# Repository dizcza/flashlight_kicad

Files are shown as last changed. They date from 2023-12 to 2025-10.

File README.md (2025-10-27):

# Flashlight PCB design with wooden casing

Kicad PCB design for my wooden flashlight V1 (see https://github.com/dizcza/lasercut_collection). Originally designed by HackLabKyiv residents.

An ordinary 12V LED strip is soldered to the front side of the PCB.

<table>
  <tr>
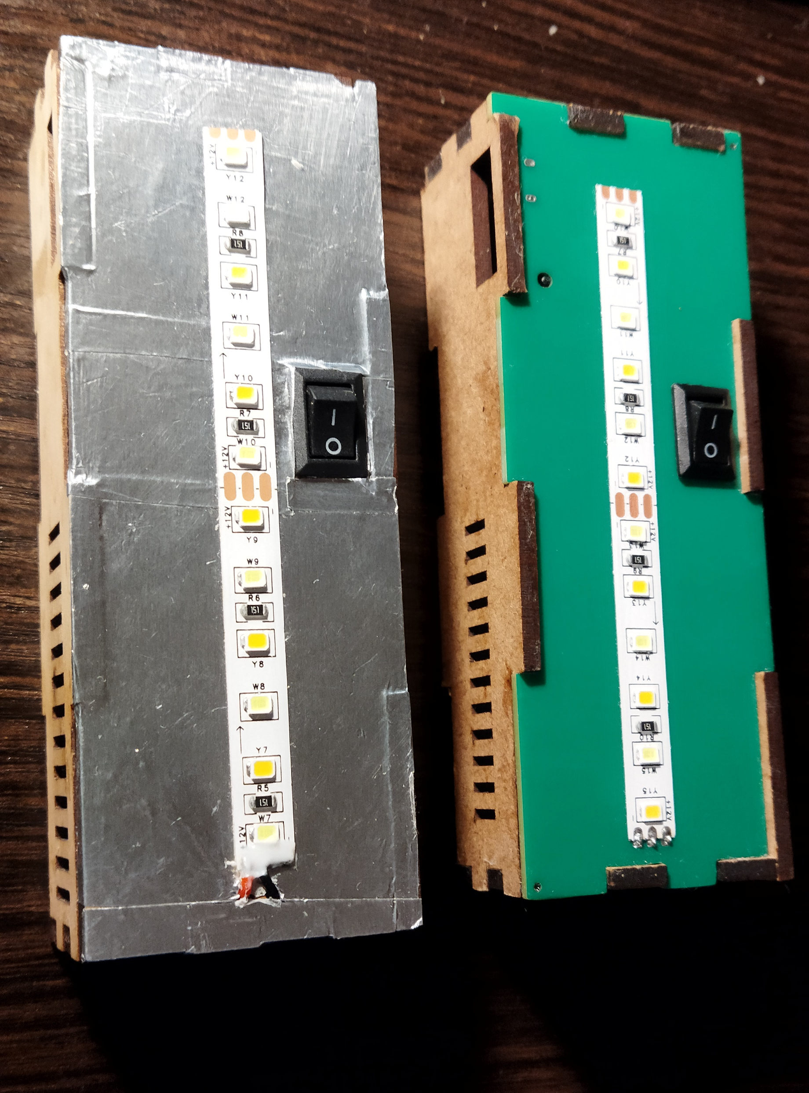
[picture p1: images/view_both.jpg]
   <td></td>
   <td></td>
  </tr>
</table>

## Schematics

[schematics.pdf](schematics.pdf)

## Revisions

<table>
  <tr>
   <th>V1</th>
   <th>V2.1</th>
   <th>V2.2</th>
   <th>V3.0</th>
  </tr>
  <tr>
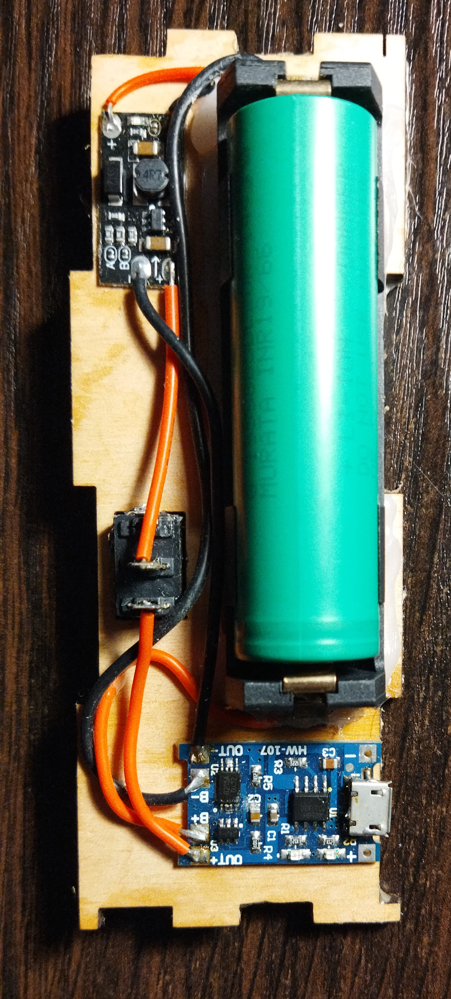
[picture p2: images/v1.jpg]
   <td></td>
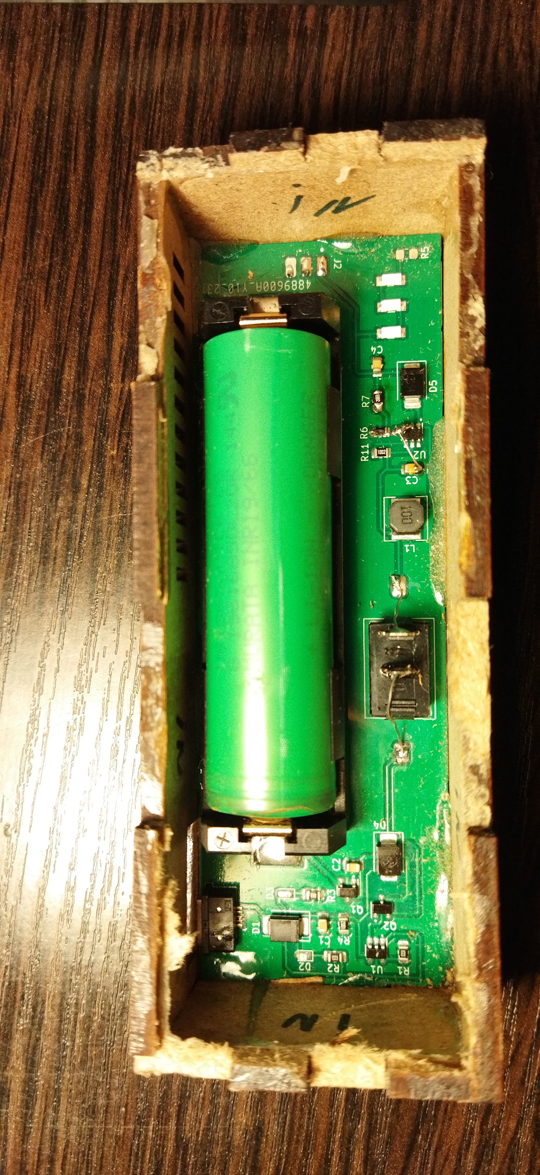
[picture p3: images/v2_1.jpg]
   <td></td>
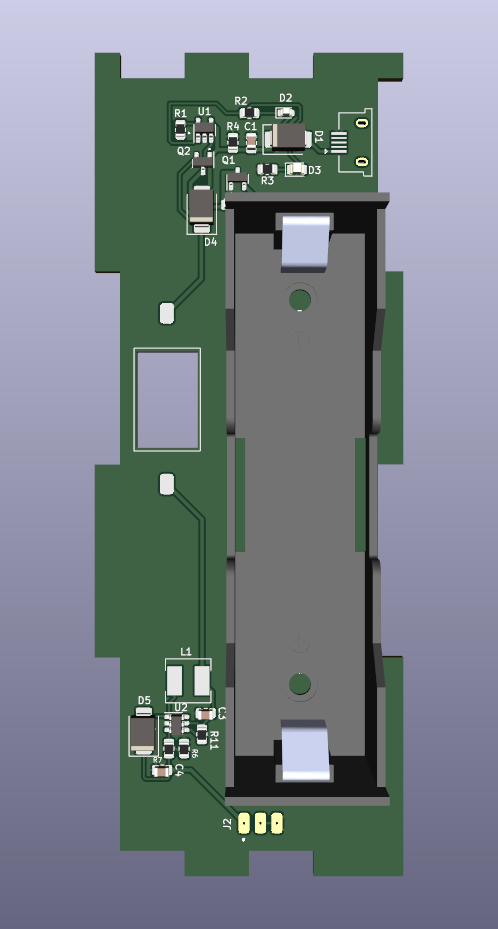
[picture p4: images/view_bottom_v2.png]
   <td></td>
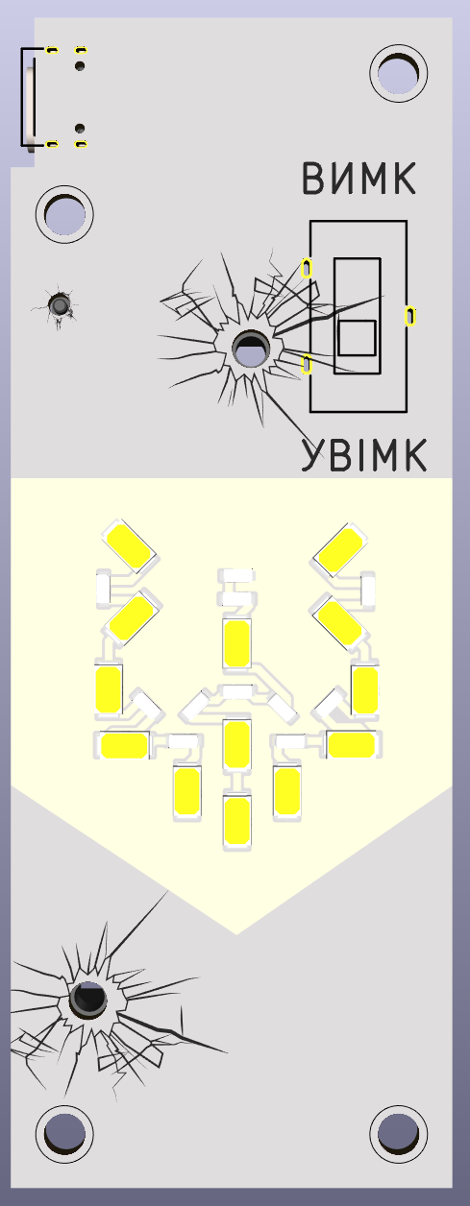
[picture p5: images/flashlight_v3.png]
   <td></td>
  </tr>
</table>

## BOM

|Comment |Designator|Footprint |LCSC |
|---|---|---|---|
|22uF/25V |C1,C3,C4  |Capacitor_SMD:C_0805_2012Metric|C45783  |
|1uF |C2 |Capacitor_SMD:C_0603_1608Metric|C15849  |
|D_Schottky |D1,D4,D5  |Diode_SMD:D_SMB |C22452  |
|USB_B_Micro |J1 |FlashlightLib:USB-1101IPX6-02  |C2858269|
|10uH |L1 |FlashlightLib:L_5.0x5.0 |C2849501|
|HSS2333 |Q2 |Package_TO_SOT_SMD:SOT-23 |C15127  |
|1k |R1,R2,R3  |Resistor_SMD:R_0603_1608Metric |C21190  |
|10k |R4,R6 |Resistor_SMD:R_0603_1608Metric |C25804  |
|200k |R7 |Resistor_SMD:R_0603_1608Metric |C25811  |
|XB4908A |U1 |FlashlightLib:XB4908A |C2998740|
|MT3608 |U2 |Package_TO_SOT_SMD:SOT-23-6 |C84817  |
|TP4057 |U3 |Package_TO_SOT_SMD:TSOT-23-6 |C12044  |
|R6BHC-A05_LED-19-223|U4 |MyFootprints:R6BHC-A05_LED |C131286 |

## Casing

Can be lasercut or 3d-printed.



DXF file: [casing.dxf](./casing/casing.dxf)

OpenSCAD design file: https://github.com/dizcza/lasercut_collection/blob/master/Lampa.scad

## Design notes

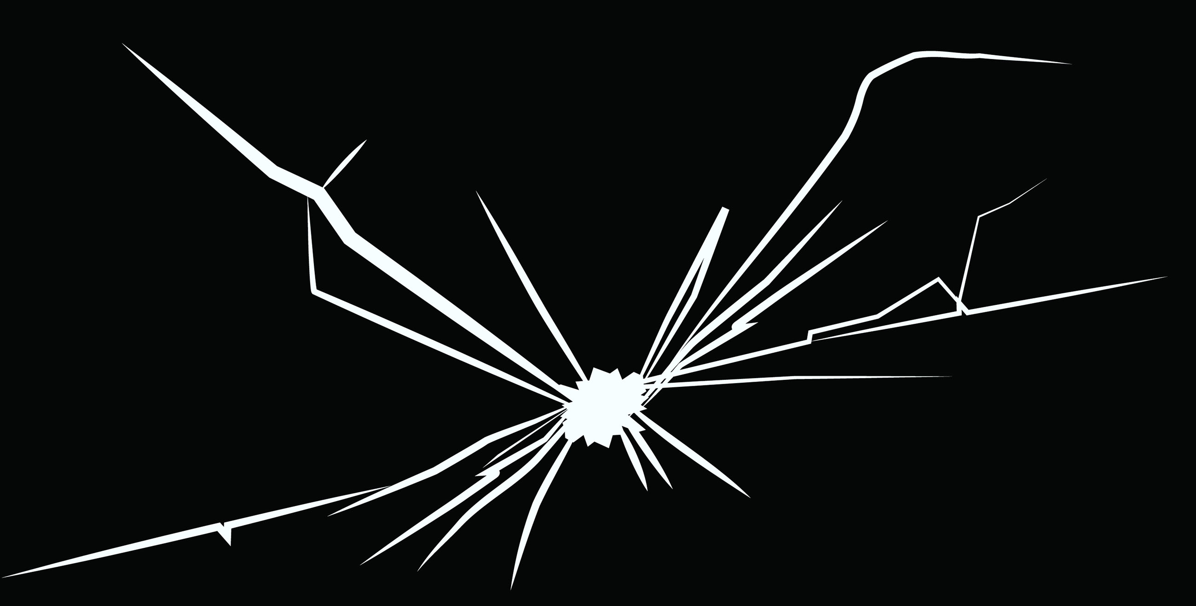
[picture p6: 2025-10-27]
images/bullet-hole/patch1.png

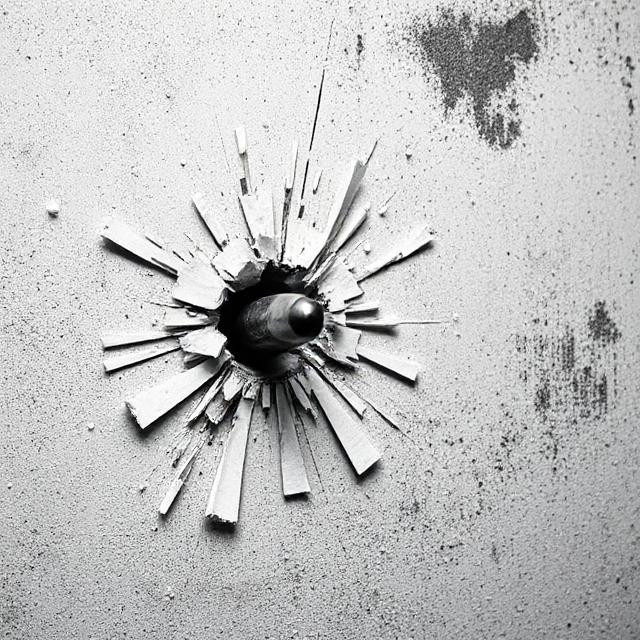
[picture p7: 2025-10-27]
images/bullet-hole/ai3.jpeg

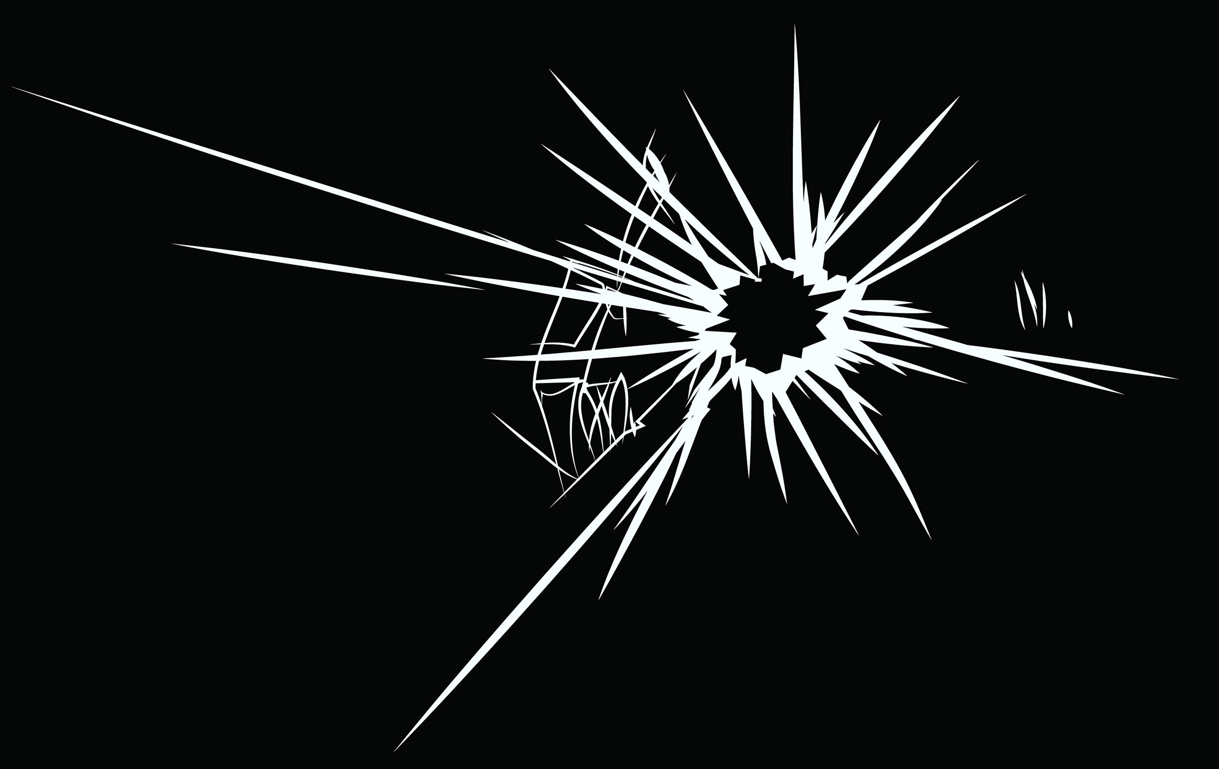
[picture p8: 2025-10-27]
images/bullet-hole/patch3.png

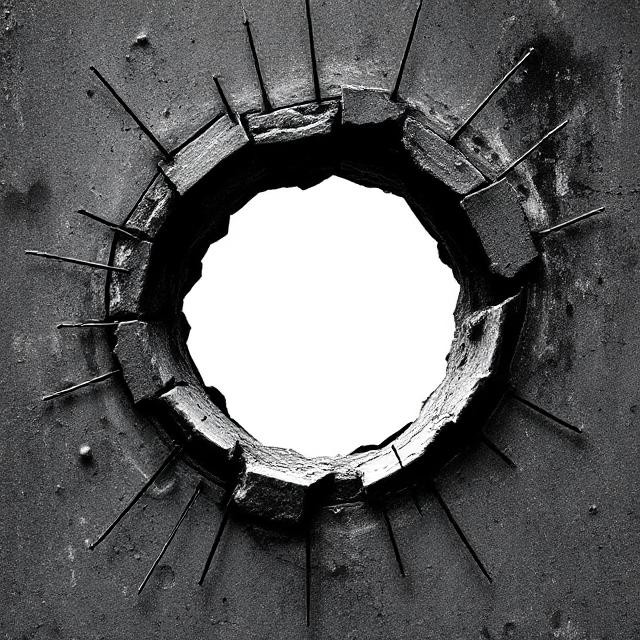
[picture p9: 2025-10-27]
images/bullet-hole/ai4.jpg

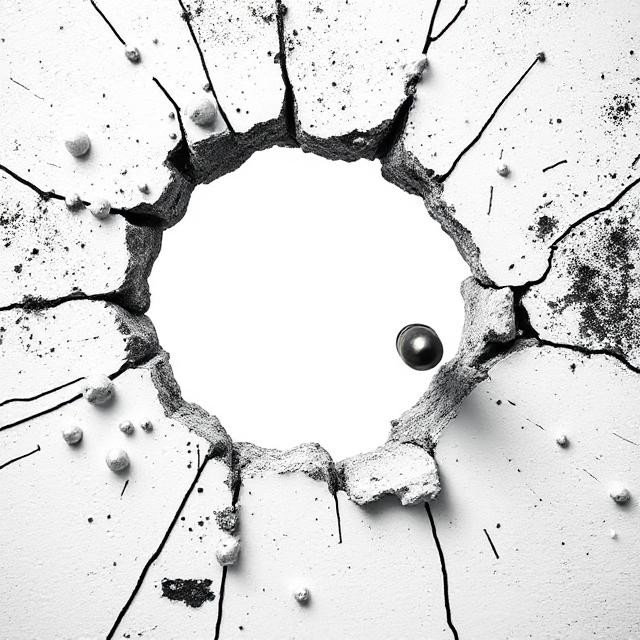
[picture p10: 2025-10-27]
images/bullet-hole/ai2.jpeg

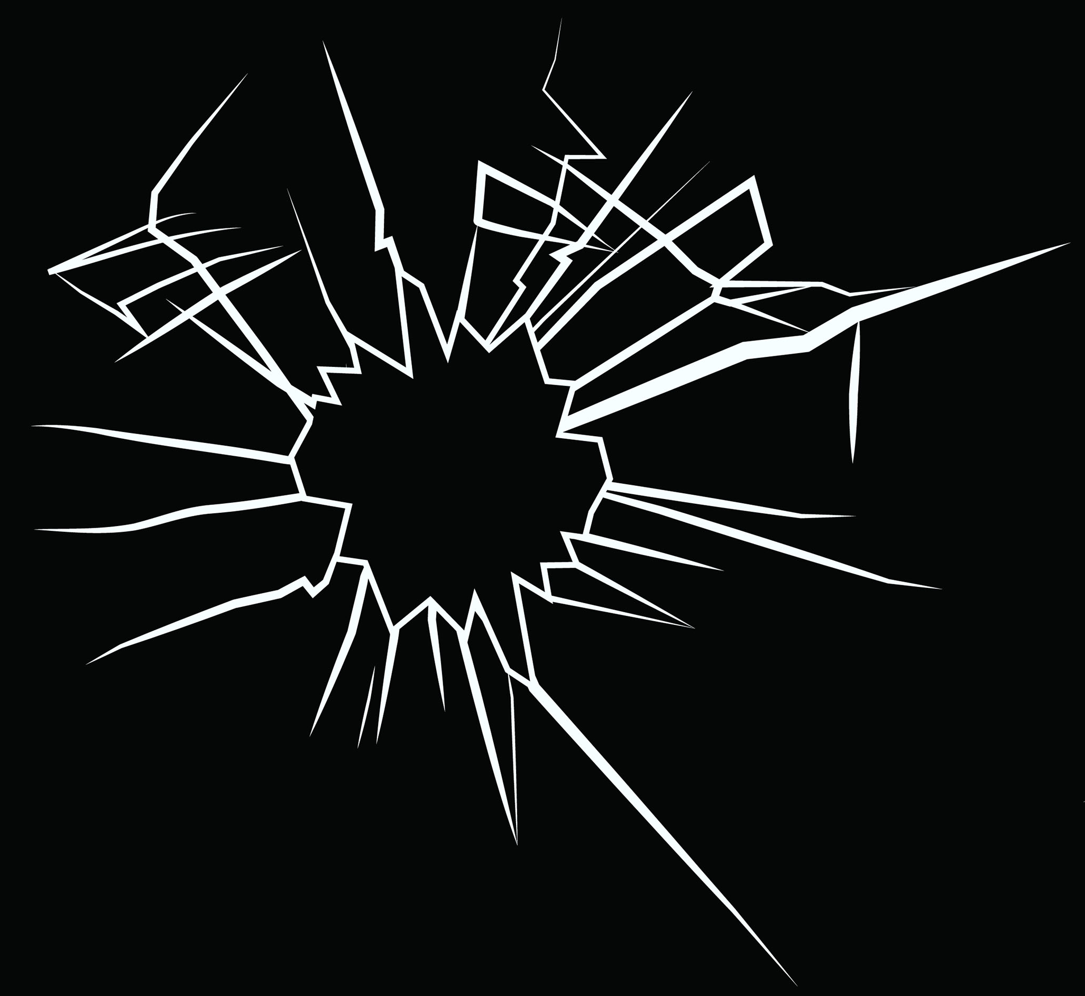
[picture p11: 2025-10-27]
images/bullet-hole/patch2.png

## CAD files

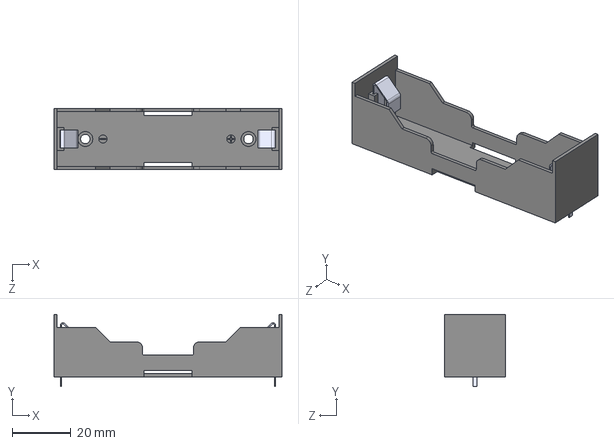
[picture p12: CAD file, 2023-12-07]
3dmodels/BH-18650-PC--3DModel-STEP-56544.STEP
77.7 x 24.6 x 20.9 mm

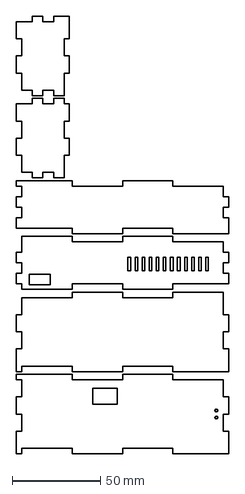
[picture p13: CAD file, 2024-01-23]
casing/casing.dxf
120.0 x 247.8 mm

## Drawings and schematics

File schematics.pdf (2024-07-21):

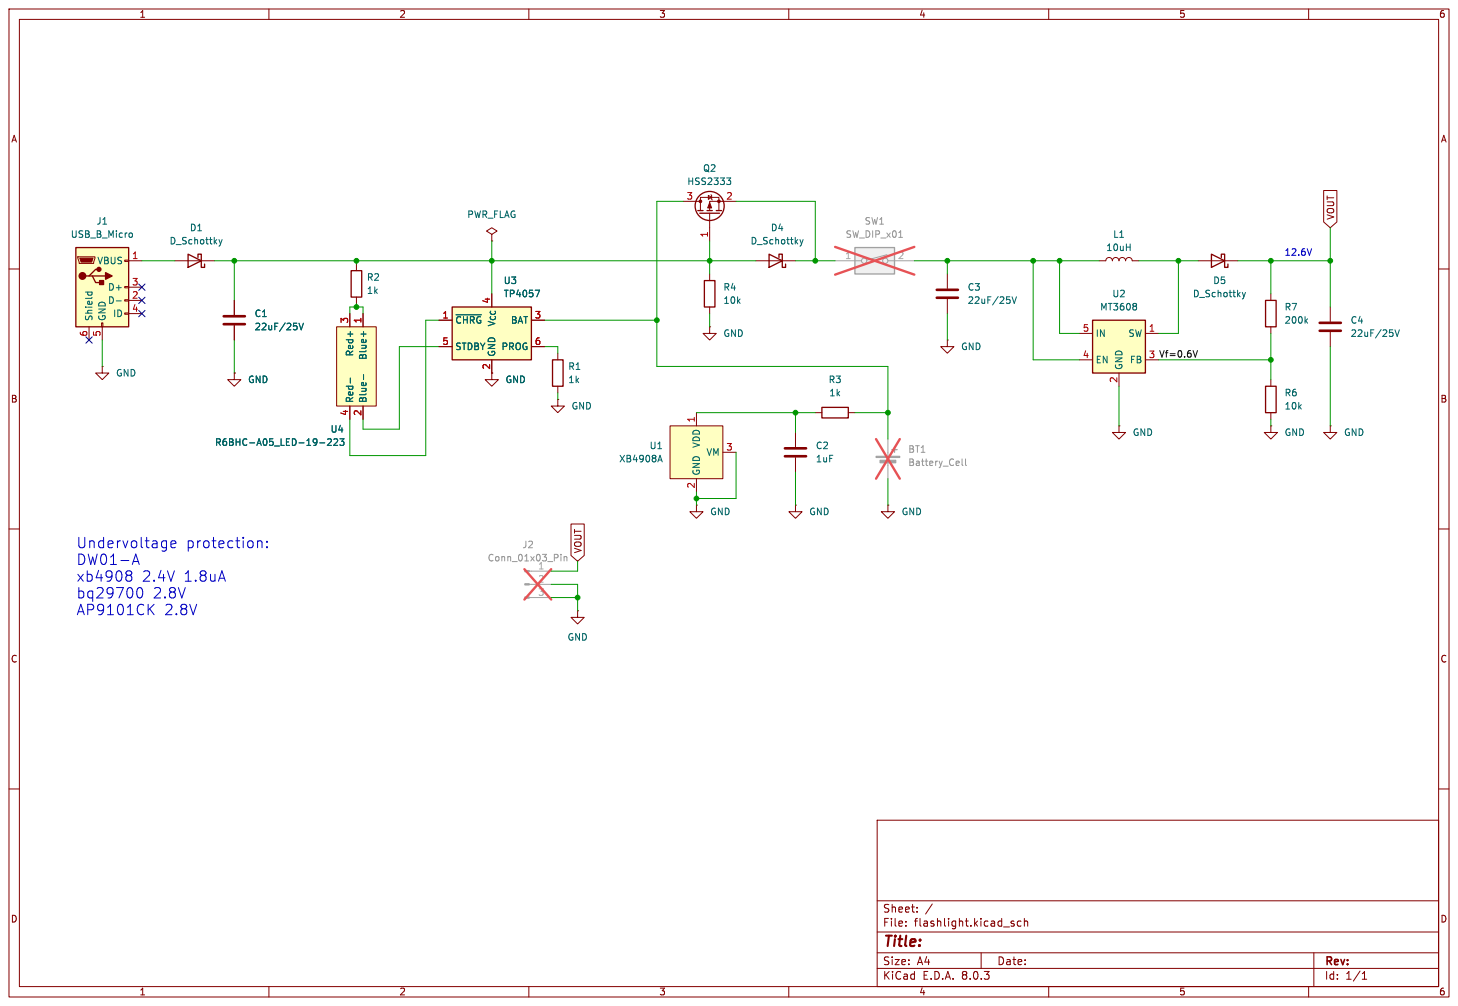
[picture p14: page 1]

2 BAT 3 V_{CC} 4 STDBY 5 PROG 6 U3 TP4057 GND VDD

2 BAT 3 V_{CC} 4 STDBY 5 PROG 6 C1

Id: 1/1 Title: File: flashlight.kicad_sch Sheet: /

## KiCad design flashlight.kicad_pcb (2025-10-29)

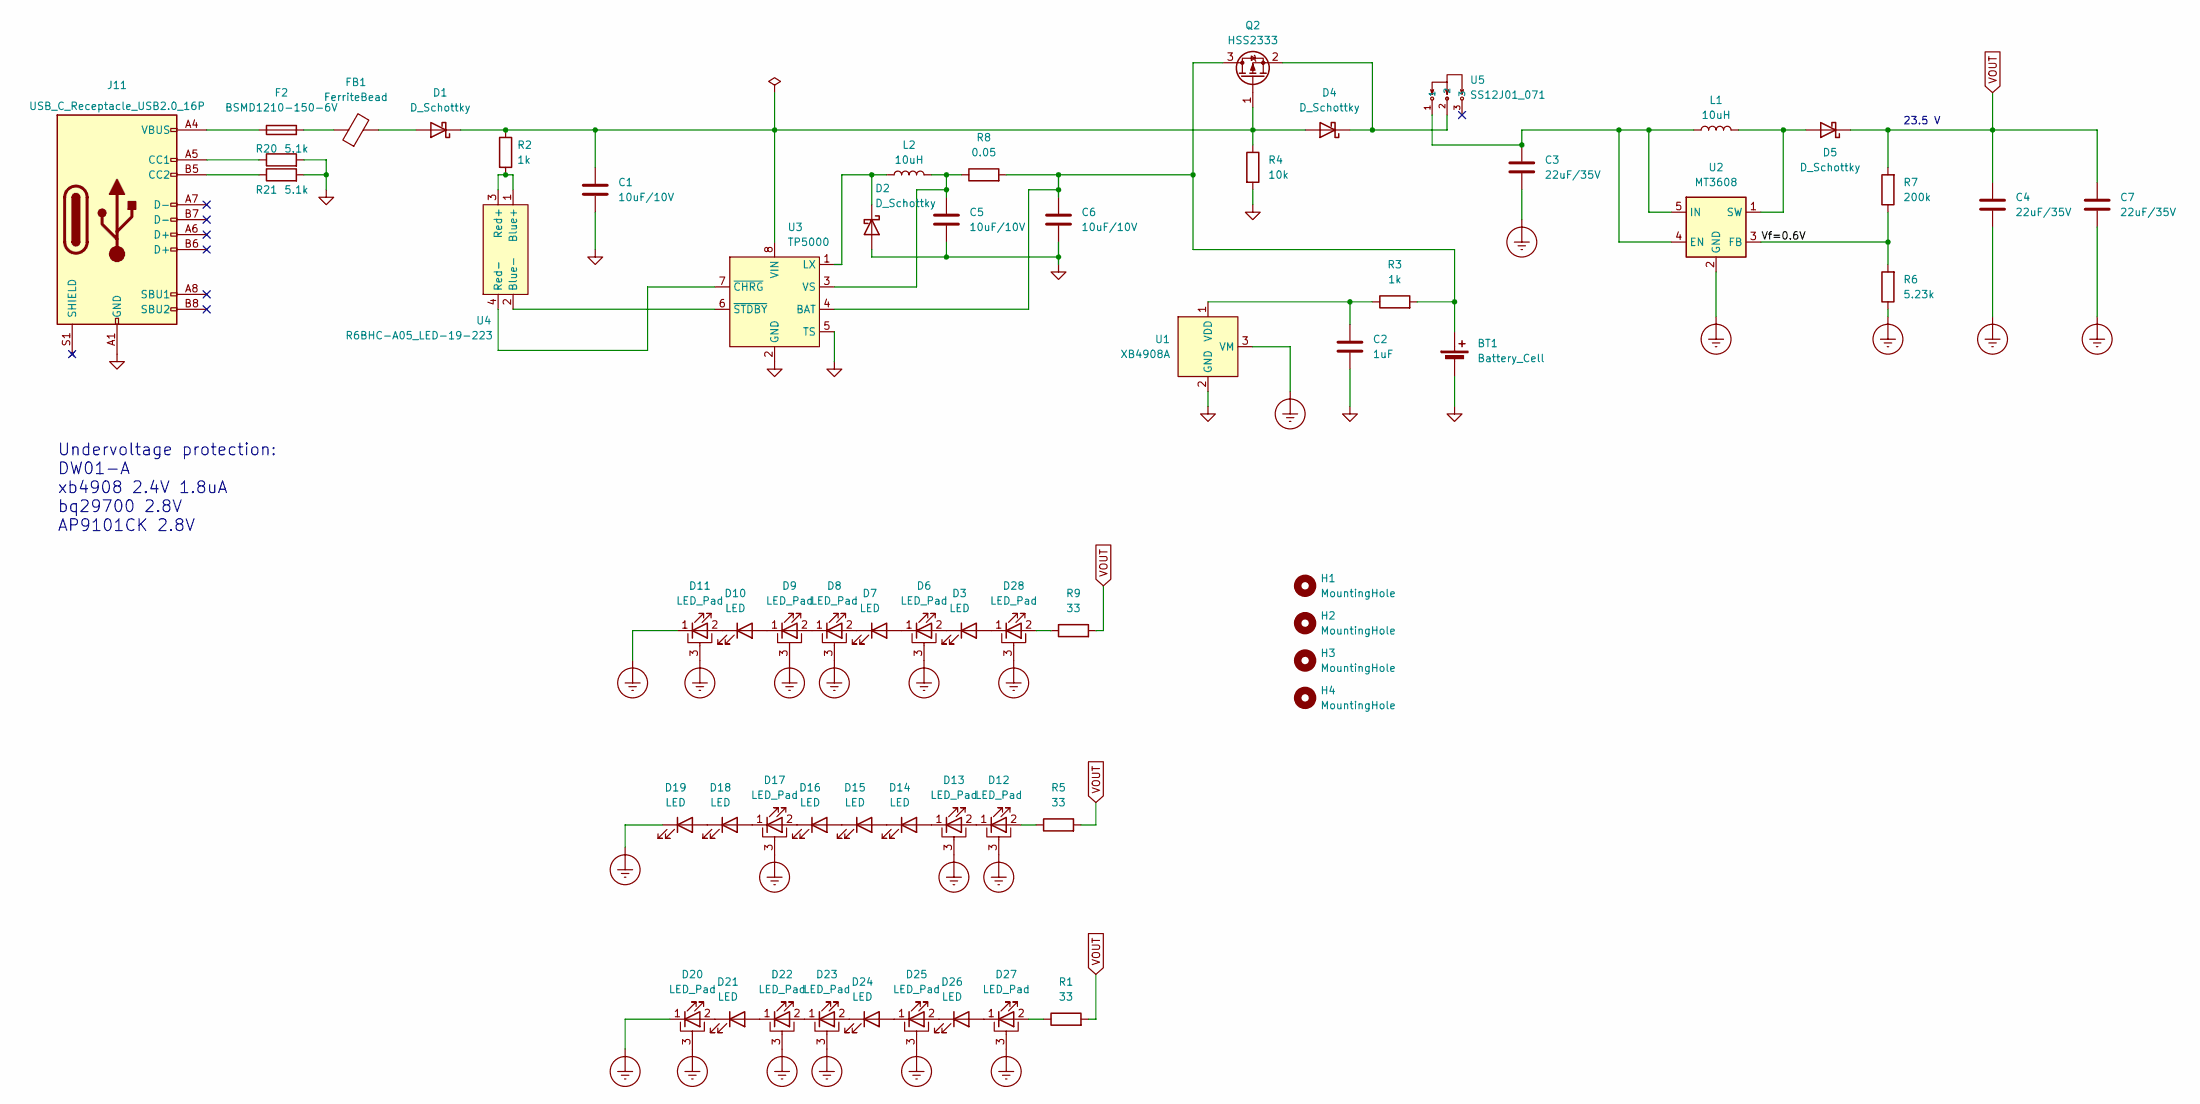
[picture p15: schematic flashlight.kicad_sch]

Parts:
BT1: Battery_Cell; BAT-SMD_L82.5.5-W25-BH-21700-B1BJ001; LCSC C20606791
C1, C5, C6: 10uF/10V; C_0603_1608Metric; LCSC C19702
C2: 1uF; C_0603_1608Metric; LCSC C15849
C3, C4, C7: 22uF/35V; C_0805_2012Metric; LCSC C6119901
D1, D2, D4, D5: D_Schottky; D_SMB; LCSC C22452
D3, D7, D10, D14, D15, D16, D18, D19, D21, D24, D26: LED; LED-SMD_L3.0-W1.4-RD_WHITE; LCSC C2843791
D6, D8, D9, D11, D12, D13, D17, D20, D22, D23, D25, D27, D28: LED_Pad; LED-SMD_3P-L5.7-W3.0-RD; LCSC C2843887
F2: BSMD1210-150-6V; Fuse_1210_3225Metric; LCSC C960023
FB1: FerriteBead; L_0805_2012Metric; LCSC C15957
H1, H2, H3, H4: MountingHole; M4-insert
J11: USB_C_Receptacle_USB2.0_16P; USB-SMD_GT-USB-7070A01; LCSC C5446865
L1, L2: 10uH; L_5.0x5.0; LCSC C2849501
Q2: HSS2333; SOT-23; LCSC C15127
R1, R5, R9: 33; R_1206_3216Metric_Pad1.30x1.75mm_HandSolder; LCSC C18005
R2, R3: 1k; R_0603_1608Metric; LCSC C21190
R4: 10k; R_0603_1608Metric; LCSC C25804
R6: 5.23k; R_0805_2012Metric_Pad1.20x1.40mm_HandSolder; LCSC C2933464
R7: 200k; R_0603_1608Metric; LCSC C25811
R8: 0.05; R_1206_3216Metric; LCSC C912768
R20, R21: 5.1k; R_0402_1005Metric; LCSC C25905
U1: XB4908A; ESN-4_L2.8-W2.3-LS3.7-BL; LCSC C2998740
U2: MT3608; SOT23-6-Tight; LCSC C84817
U3: TP5000; ESOP-8_L4.9-W3.9-P1.27-LS6.0-BL-EP; LCSC C5447152
U4: R6BHC-A05_LED-19-223; LED-ARRAY-SMD_4P-L1.6-W1.3-BR-FD; LCSC C131286
U5: SS12J01_071; SW-TH_SHOU-HAN_SS12J01; LCSC C2887258

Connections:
/Vf=0.6V: R6.2, R7.1, U2.3 (FB)
Earth_Protective: C3.2, C4.2, C7.2, D6.3 (PAD), D8.3 (PAD), D9.3 (PAD), D11.1 (K), D11.3 (PAD), D12.3 (PAD), D13.3 (PAD), D17.3 (PAD), D19.1 (K), D20.1 (K), D20.3 (PAD), D22.3 (PAD), D23.3 (PAD), D25.3 (PAD), D27.3 (PAD), D28.3 (PAD), R6.1, U1.3 (VM), U1.4 (VM), U2.2 (GND)
GND: BT1.2 (-), C1.2, C2.2, C5.2, C6.2, D2.2 (A), J11.A1 (GND), J11.A12 (GND), J11.B1 (GND), J11.B12 (GND), R4.2, R20.2, R21.2, U1.2 (GND), U3.2 (GND), U3.5 (TS), U3.9 (GND)
unnamed: BT1.1 (+), C6.1, Q2.3 (D), R3.2, R8.2, U3.4 (BAT)
unnamed: D1.2 (A), FB1.2
unnamed: C1.1, D1.1 (K), D4.2 (A), Q2.1 (G), R2.1, R4.1, U3.8 (VIN)
unnamed: D2.1 (K), L2.1, U3.1 (LX)
unnamed: D3.1 (K), D6.2 (A)
unnamed: D4.1 (K), Q2.2 (S), U5.2
unnamed: D5.2 (A), L1.2, U2.1 (SW)
unnamed: D6.1 (K), D7.2 (A)
unnamed: D7.1 (K), D8.2 (A)
unnamed: D8.1 (K), D9.2 (A)
unnamed: D9.1 (K), D10.2 (A)
unnamed: D10.1 (K), D11.2 (A)
unnamed: D12.2 (A), R5.1
unnamed: D12.1 (K), D13.2 (A)
unnamed: D13.1 (K), D14.2 (A)
unnamed: D14.1 (K), D15.2 (A)
unnamed: D15.1 (K), D16.2 (A)
unnamed: D16.1 (K), D17.2 (A)
unnamed: D17.1 (K), D18.2 (A)
unnamed: D18.1 (K), D19.2 (A)
unnamed: D20.2 (A), D21.1 (K)
unnamed: D21.2 (A), D22.1 (K)
unnamed: D22.2 (A), D23.1 (K)
unnamed: D23.2 (A), D24.1 (K)
unnamed: D24.2 (A), D25.1 (K)
unnamed: D25.2 (A), D26.1 (K)
unnamed: D26.2 (A), D27.1 (K)
unnamed: D27.2 (A), R1.1
unnamed: D28.2 (A), R9.1
unnamed: D3.2 (A), D28.1 (K)
unnamed: F2.1, J11.A4 (VBUS), J11.A9 (VBUS), J11.B4 (VBUS), J11.B9 (VBUS)
unnamed: F2.2, FB1.1
unnamed: J11.A5 (CC1), R20.1
unnamed: J11.B5 (CC2), R21.1
unnamed: C2.1, R3.1, U1.1 (VDD)
unnamed: C3.1, L1.1, U2.4 (EN), U2.5 (IN), U5.1
unnamed: C5.1, L2.2, R8.1, U3.3 (VS)
unnamed: U3.7 (~CHRG), U4.4 (Red-)
unnamed: U3.6 (~STDBY), U4.2 (Blue-)
unnamed: R2.2, U4.1 (Blue+), U4.3 (Red+)
VOUT: C4.1, C7.1, D5.1 (K), R1.2, R5.2, R7.2, R9.2

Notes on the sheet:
23.5 V
Undervoltage protection: DW01-A xb4908 2.4V 1.8uA bq29700 2.8V AP9101CK 2.8V

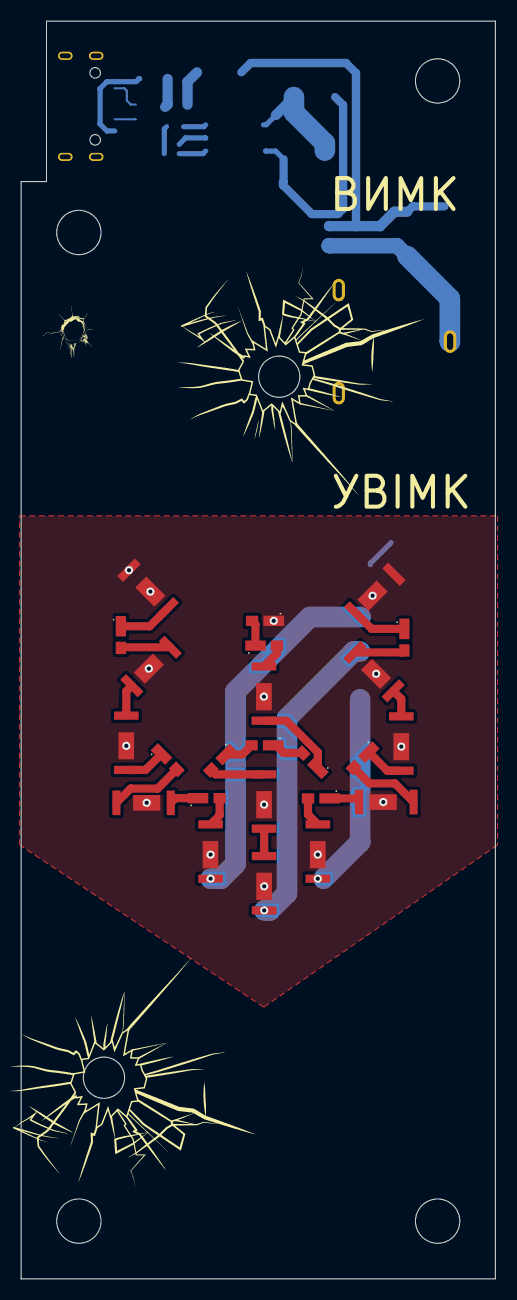
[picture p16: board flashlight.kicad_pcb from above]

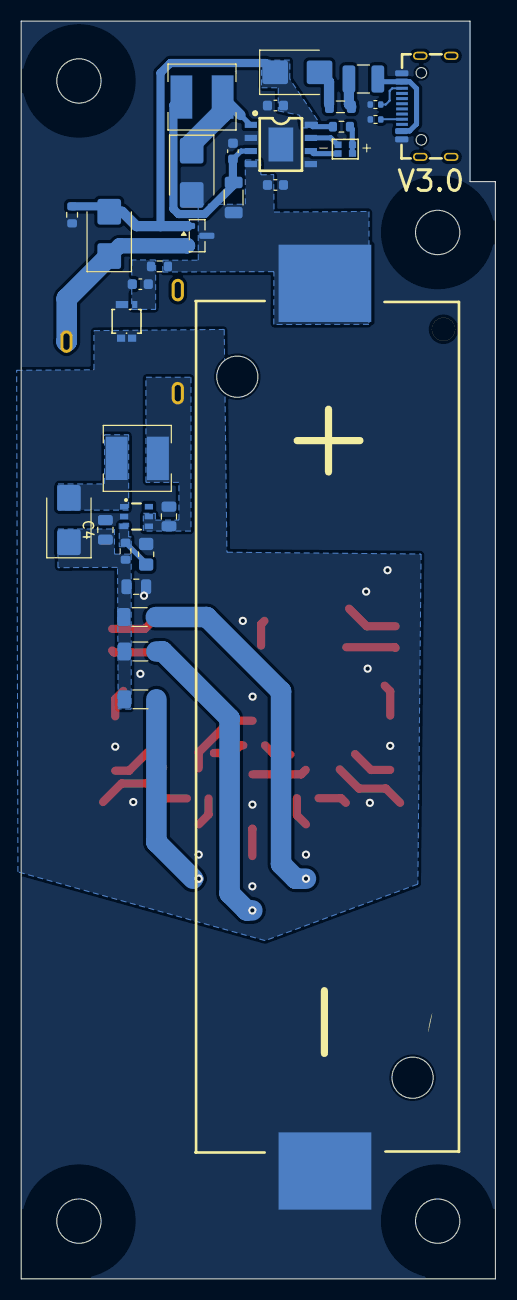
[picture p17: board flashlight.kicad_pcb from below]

Board: 2 copper layers, 46.0 x 122.0 mm, 62 parts (33 on the bottom side), 44 nets.

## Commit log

2023-12-08 jlcpcb completed
    [flashlight.csv, flashlight.kicad_pcb, flashlight.kicad_sch]
2023-12-08 18.24 Volts 4.70
    [flashlight.kicad_pcb]
2023-12-08 led strip
    [flashlight.csv, flashlight.kicad_pcb, flashlight.kicad_sch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]
2023-12-09 JLCPCB ordered
    [flashlight.csv, flashlight.kicad_pcb, flashlight.kicad_sch]
2024-01-22 shortened GND paths
    [flashlight.csv, flashlight.kicad_pcb, flashlight.kicad_sch]
2024-01-22 added schematics
2024-01-23 upd v2.2
    [casing.dxf, flashlight.csv, flashlight.kicad_pcb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]
2024-01-23 0603 footprint
    [flashlight.kicad_pcb, flashlight.kicad_sch]
2024-01-25 copper pour
    [flashlight.kicad_pcb]
2024-01-28 tight sot23-6
    [flashlight.kicad_pcb, flashlight.kicad_sch]
2024-06-21 v2.4: double led
    [flashlight.kicad_pcb, flashlight.kicad_sch]
2024-07-21 v2.4 xb4908A undervoltage protection
    [flashlight.kicad_pcb, flashlight.kicad_sch]
2024-08-10 increased 18650 pads size, added led stripe silkscreen line, increased switch hole length by 0.1mm
    [flashlight.kicad_pcb, flashlight.kicad_sch]
2024-08-15 xb4908 v2.5
    [flashlight.kicad_pcb, flashlight.kicad_sch]
2024-09-14 moved TP4057 closer to the VBAT
    [flashlight.kicad_pcb, flashlight.kicad_sch]
2024-09-14 v2.6: board outline 4mm
    [flashlight.kicad_pcb]
2024-11-11 v2.7 boxes
    [flashlight.kicad_pcb, flashlight.kicad_sch]
2025-10-27 V3.0 21700 3x8 leds
    [flashlight.kicad_pcb, flashlight.kicad_sch]
2025-10-27 bullet hole images
2025-10-28 fixed C4 cap issue
    [flashlight.kicad_pcb]
2025-10-29 Added an extra out capacitor
    [flashlight.kicad_pcb, flashlight.kicad_sch]
